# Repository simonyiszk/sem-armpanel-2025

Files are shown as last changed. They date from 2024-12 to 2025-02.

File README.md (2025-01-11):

# STM32F070 mikrokontrolleres ARM fejlesztőpanel a<br/> Schönherz Elektronikai Műhely 2025-ös<br/> alapozó tanfolyamához

Fícsörök:
- Kenyérvágódeszkával kompatibilis kialakítás
- Feliratozott lábak
- USB-C csatlakozó
- Integrált CMSIS-DAP programozó áramkör
- Visszajelző LED-ek: tápfeszültség, programozó/debugger üzemmód, valamint USER LED a PA6-os lábon
- RESET gomb

A mikrovezérlőhöz tartozó dokumentáció itt érhető el:<br/> [https://www.st.com/en/microcontrollers-microprocessors/stm32f070f6.html#documentation](https://www.st.com/en/microcontrollers-microprocessors/stm32f070f6.html#documentation)
  
DSCN0155

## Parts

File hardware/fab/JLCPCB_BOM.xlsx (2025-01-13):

Comment | Designator | Footprint | JLCPCB Part #（optional）
100n | C5,C2,C4 | C_0603_1608Metric | C14663
RED | D2,D3,D1 | LED_0603_1608Metric | C2286
LD1117S33TR_SOT223 | U2 | SOT-223-3_TabPin2 | C6186
10u | C3,C1 | C_0805_2012Metric | C15850
10k | R6,R7,R5 | R_0603_1608Metric | C25804
STM32F030F4Px | U1 | TSSOP-20_4.4x6.5mm_P0.65mm | C86951
1A | F1 | Fuse_1206_3216Metric | C883131
1k | R1,R2,R8 | R_0603_1608Metric | C21190
5k1 | R4,R3 | R_0603_1608Metric | C23186
CH32V203G6U6 | U3 | QFN-28-1EP_4x4mm_P0.4mm_EP2.8x2.8mm | C5142280
USB_C_Receptacle_USB2.0_16P | J1 | USB_C_Receptacle_G-Switch_GT-USB-7010ASV | C2927038

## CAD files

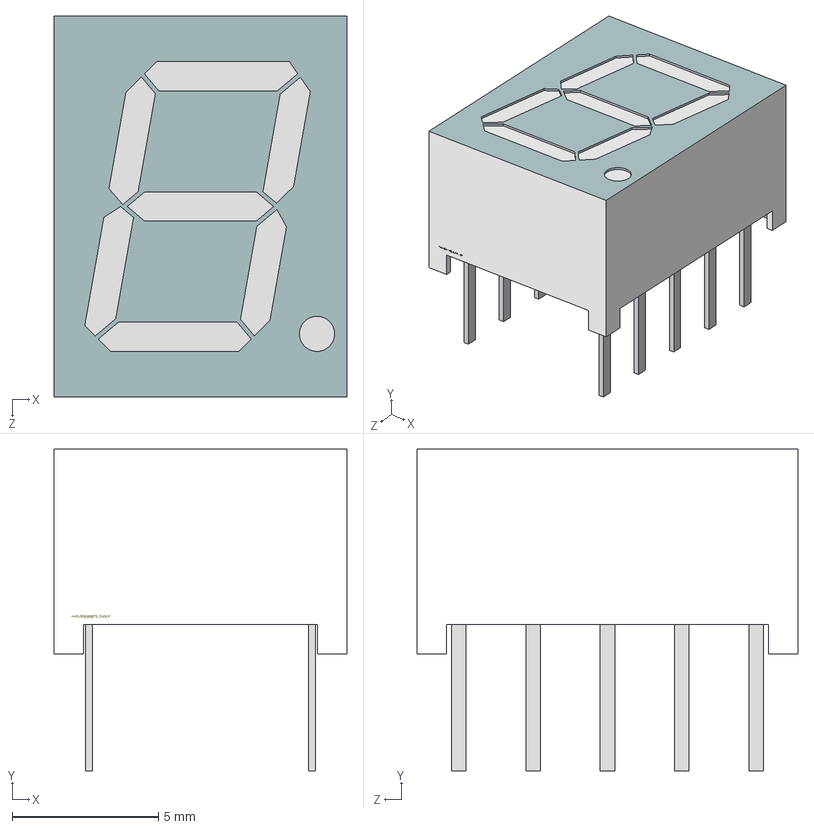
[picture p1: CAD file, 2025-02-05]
alappanel/SA39-11.STEP
10.0 x 11.0 x 13.0 mm

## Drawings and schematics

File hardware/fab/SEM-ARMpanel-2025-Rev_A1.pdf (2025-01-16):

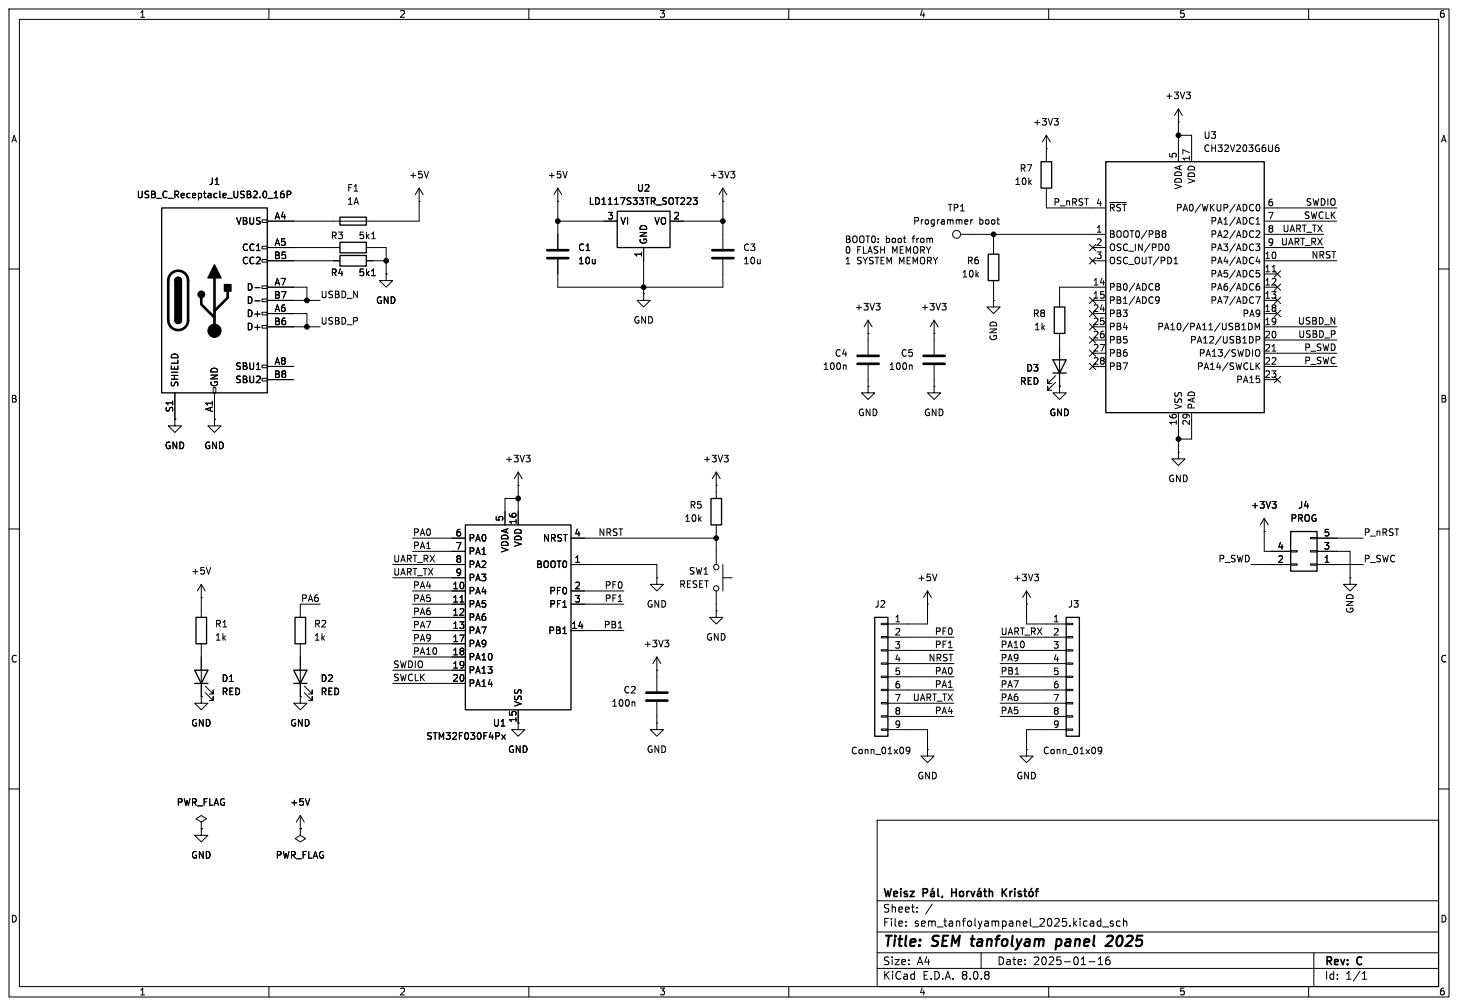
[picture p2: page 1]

Id: 1/1 Title: SEM tanfolyam panel 2025

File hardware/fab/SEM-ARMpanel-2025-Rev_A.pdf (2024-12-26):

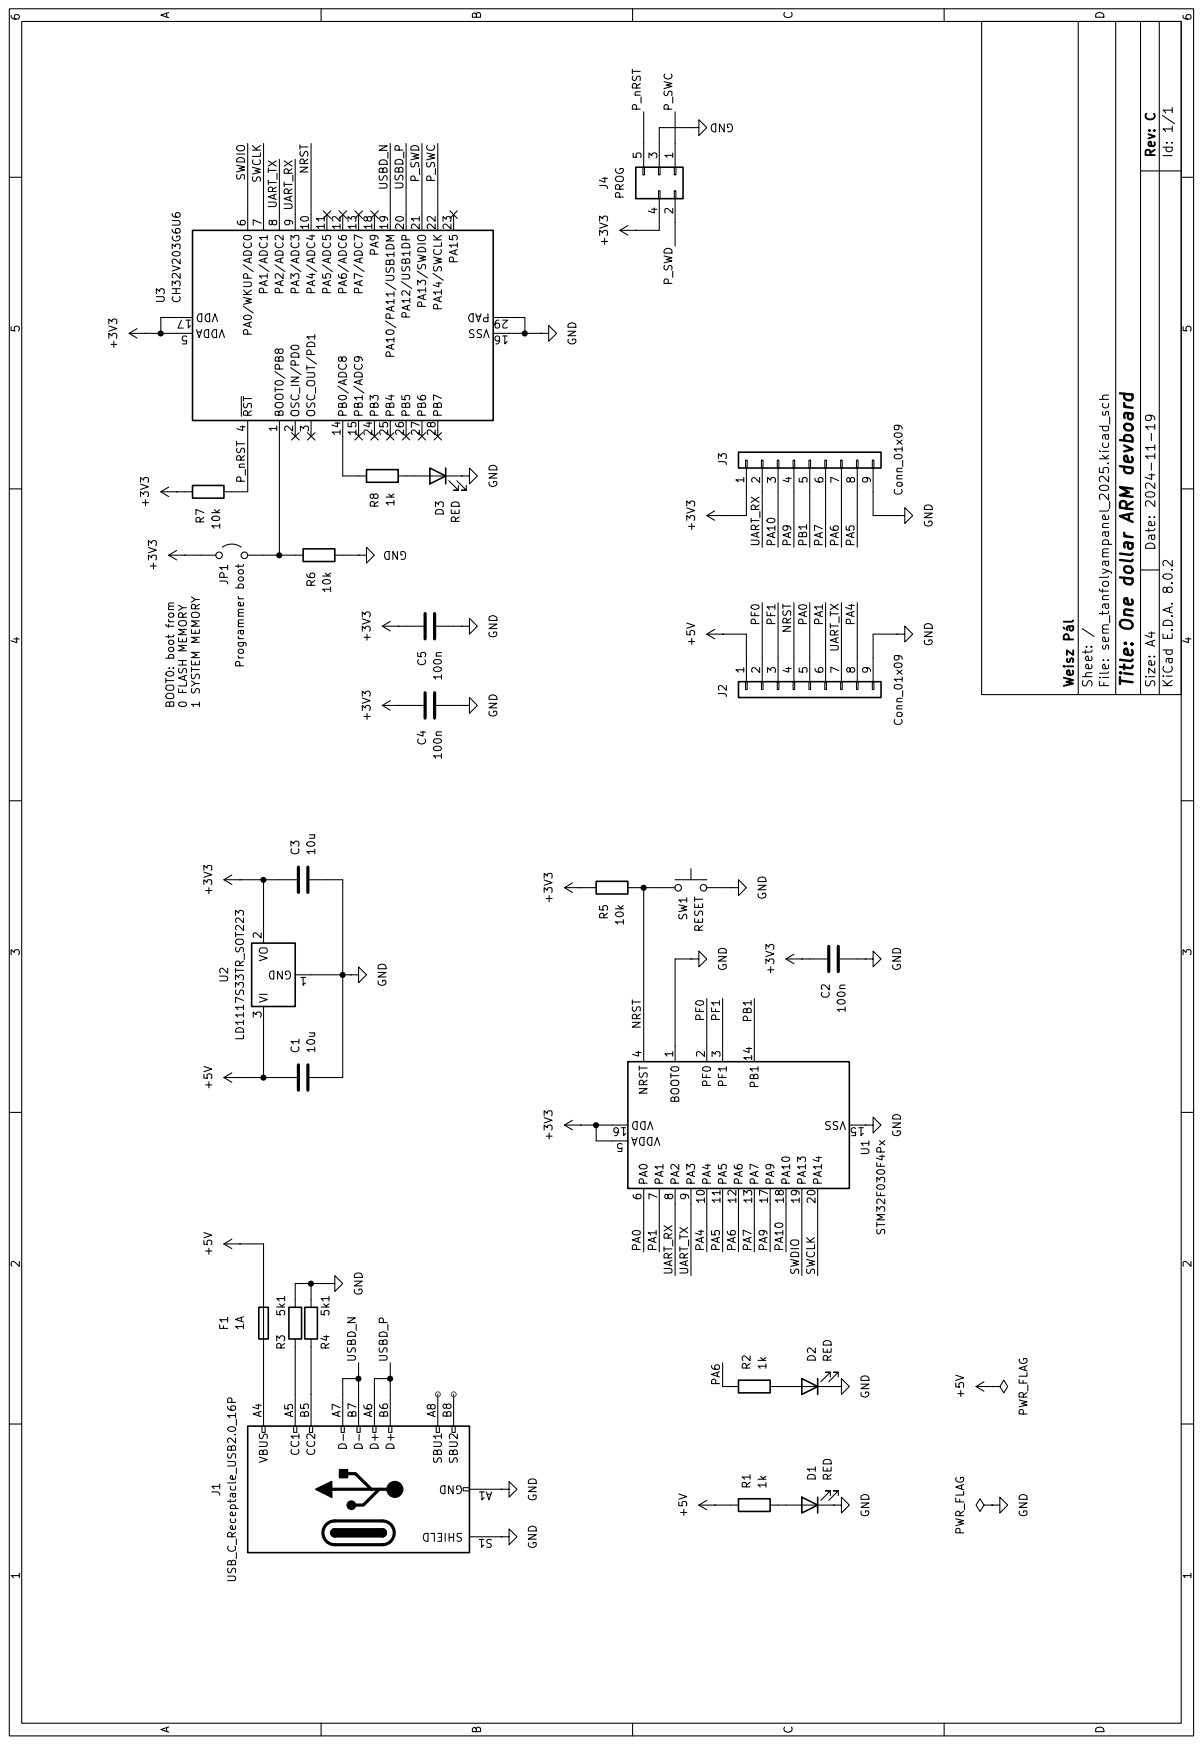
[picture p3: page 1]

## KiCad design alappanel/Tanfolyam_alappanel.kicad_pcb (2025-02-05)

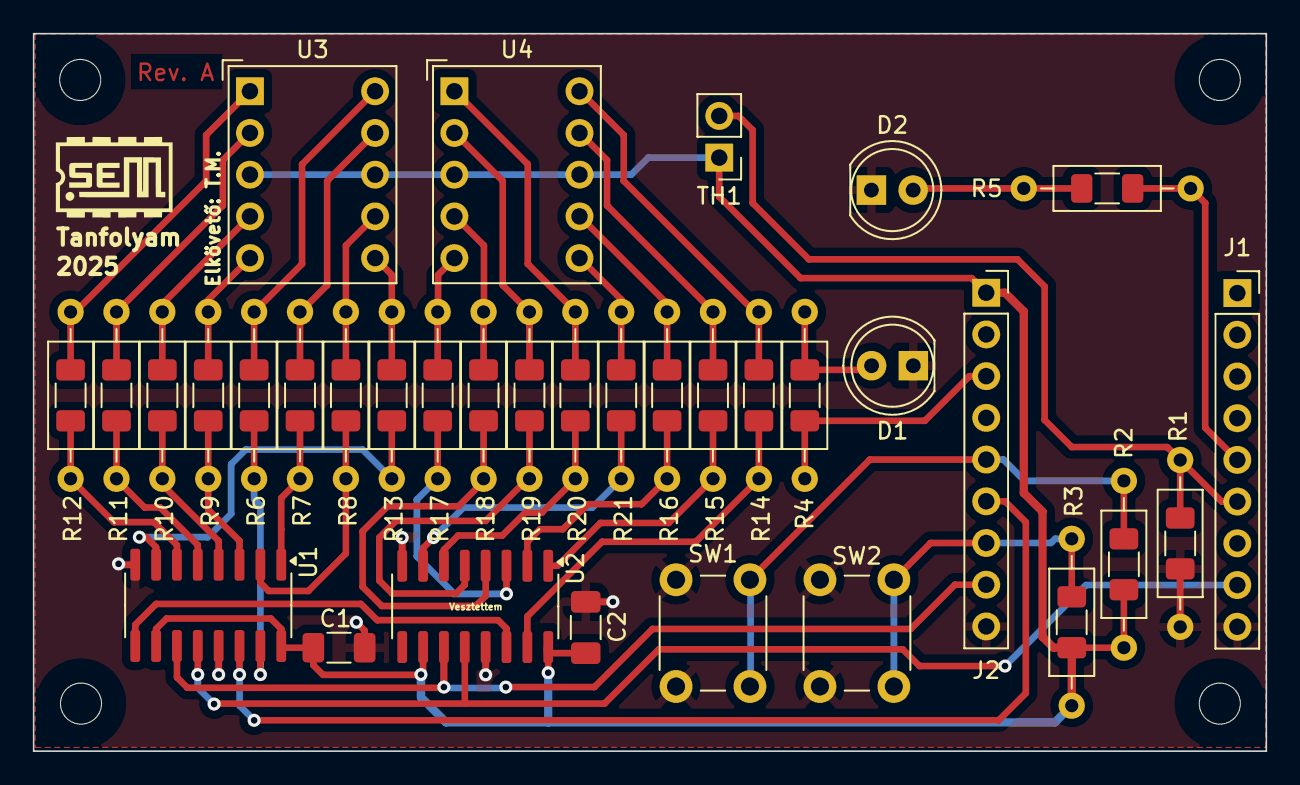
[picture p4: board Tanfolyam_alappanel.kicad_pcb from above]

Board: 2 copper layers, 75.1 x 43.7 mm, 34 parts (0 on the bottom side), 45 nets.

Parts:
C1, C2: 100n; C_1206_3216Metric_Pad1.33x1.80mm_HandSolder
D1, D2: LED; LED_D5.0mm
J1, J2: Connector; PinSocket_1x09_P2.54mm_Vertical
R1, R2, R3: 10k; R_1206_THT
R4, R5, R6, R7, R8, R9, R10, R11, R12, R13, R14, R15, R16, R17, R18, R19, R20, R21: 220; R_1206_THT
SW1, SW2: SW_Push; SW_PUSH_6mm
TH1: NTC; PinHeader_1x02_P2.54mm_Vertical
U1, U2: 74HC595; SOIC-16_3.9x9.9mm_P1.27mm
U3, U4: SA39-11SRWA; Sx39-1xxxxx

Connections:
+3.3V: C1.1, C2.1, J2.1, R2.1, R3.1, TH1.1, U1.10 (~SRCLR), U1.16 (VCC), U2.10 (~SRCLR), U2.16 (VCC), U3.3 (CA), U3.8 (CA), U4.3 (CA), U4.8 (CA)
/PA0: J1.5, R5.1
/PA1: J1.6, R1.1, TH1.2
/PA4: J1.8, U1.12 (RCLK), U2.12 (RCLK)
/PA5: J2.8, U1.11 (SRCLK), U2.11 (SRCLK)
/PA6: J2.7, R3.2, SW2.1
/PA7: J2.6, U1.14 (SER)
/PA10: J2.3, R4.1
/PB1: J2.5, R2.2, SW1.1
GND: C1.2, C2.2, D1.1 (K), D2.1 (K), J1.9, J2.9, R1.2, SW1.2, SW2.2, U1.8 (GND), U1.13 (~OE), U2.8 (GND), U2.13 (~OE)
unnamed: D1.2 (A), R4.2
unnamed: D2.2 (A), R5.2
unnamed: R6.1, U1.15 (QA)
unnamed: R7.1, U1.1 (QB)
unnamed: R8.1, U1.2 (QC)
unnamed: R9.1, U1.3 (QD)
unnamed: R10.1, U1.4 (QE)
unnamed: R11.1, U1.5 (QF)
unnamed: R12.1, U1.6 (QG)
unnamed: U1.9 (QH'), U2.14 (SER)
unnamed: R13.1, U1.7 (QH)
unnamed: R14.1, U2.15 (QA)
unnamed: R15.1, U2.1 (QB)
unnamed: R16.1, U2.2 (QC)
unnamed: R17.1, U2.3 (QD)
unnamed: R18.1, U2.4 (QE)
unnamed: R19.1, U2.5 (QF)
unnamed: R20.1, U2.6 (QG)
unnamed: R21.1, U2.7 (QH)
unnamed: R6.2, U3.10 (A)
unnamed: R7.2, U3.9 (B)
unnamed: R8.2, U3.7 (C)
unnamed: R9.2, U3.5 (D)
unnamed: R13.2, U3.6 (DP)
unnamed: R10.2, U3.4 (E)
unnamed: R11.2, U3.2 (F)
unnamed: R12.2, U3.1 (G)
unnamed: R14.2, U4.10 (A)
unnamed: R15.2, U4.9 (B)
unnamed: R16.2, U4.7 (C)
unnamed: R17.2, U4.5 (D)
unnamed: R21.2, U4.6 (DP)
unnamed: R18.2, U4.4 (E)
unnamed: R19.2, U4.2 (F)
unnamed: R20.2, U4.1 (G)

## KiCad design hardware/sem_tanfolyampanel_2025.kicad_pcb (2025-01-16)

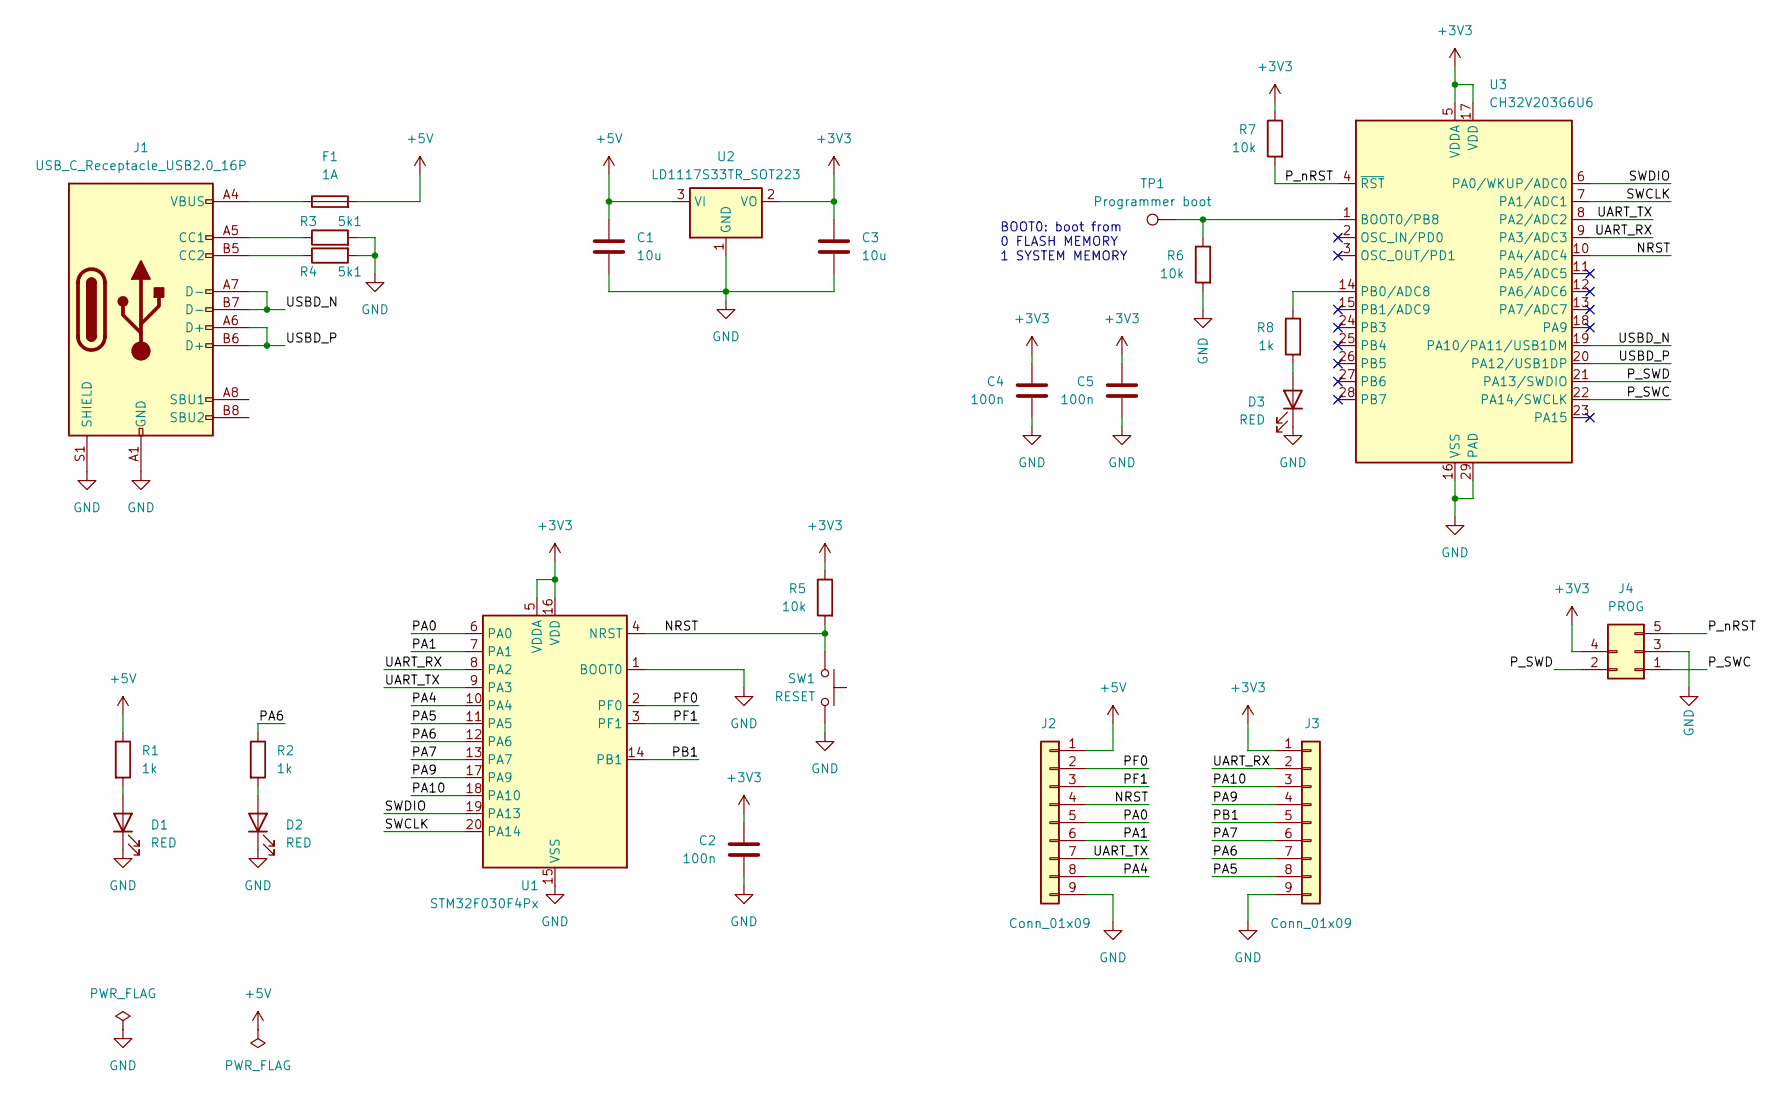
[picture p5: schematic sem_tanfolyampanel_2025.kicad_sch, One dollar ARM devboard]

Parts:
C1, C3: 10u; C_0805_2012Metric
C2, C4, C5: 100n; C_0603_1608Metric
D1, D2, D3: RED; LED_0603_1608Metric
F1: 1A; Fuse_1206_3216Metric
J1: USB_C_Receptacle_USB2.0_16P; USB_C_Receptacle_G-Switch_GT-USB-7010ASV
J2, J3: Conn_01x09; PinHeader_1x09_P2.54mm_Vertical
J4: PROG; ProgConnector_5pin
R1, R2, R8: 1k; R_0603_1608Metric
R3, R4: 5k1; R_0603_1608Metric
R5, R6, R7: 10k; R_0603_1608Metric
SW1: RESET; SW_SPST_TL3342
TP1: Programmer boot; TestPoint_THTPad_D1.5mm_Drill0.7mm
U1: STM32F030F4Px; TSSOP-20_4.4x6.5mm_P0.65mm
U2: LD1117S33TR_SOT223; SOT-223-3_TabPin2
U3: CH32V203G6U6; QFN-28-1EP_4x4mm_P0.4mm_EP2.8x2.8mm

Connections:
+3V3: C2.1, C3.1, C4.1, C5.1, J3.1, J4.4, R5.1, R7.1, U1.5 (VDDA), U1.16 (VDD), U2.2 (VO), U3.5 (VDDA), U3.17 (VDD)
+5V: C1.1, F1.2, J2.1, R1.1, U2.3 (VI)
/NRST: J2.4, R5.2, SW1.2, U1.4 (NRST), U3.10 (PA4/ADC4)
/PA0: J2.5, U1.6 (PA0)
/PA1: J2.6, U1.7 (PA1)
/PA4: J2.8, U1.10 (PA4)
/PA5: J3.8, U1.11 (PA5)
/PA6: J3.7, R2.1, U1.12 (PA6)
/PA7: J3.6, U1.13 (PA7)
/PA9: J3.4, U1.17 (PA9)
/PA10: J3.3, U1.18 (PA10)
/PB1: J3.5, U1.14 (PB1)
/PF0: J2.2, U1.2 (PF0)
/PF1: J2.3, U1.3 (PF1)
/P_SWC: J4.1, U3.22 (PA14/SWCLK)
/P_SWD: J4.2, U3.21 (PA13/SWDIO)
/P_nRST: J4.5, R7.2, U3.4 (~RST)
/SWCLK: U1.20 (PA14), U3.7 (PA1/ADC1)
/SWDIO: U1.19 (PA13), U3.6 (PA0/WKUP/ADC0)
/UART_RX: J3.2, U1.8 (PA2), U3.9 (PA3/ADC3)
/UART_TX: J2.7, U1.9 (PA3), U3.8 (PA2/ADC2)
/USBD_N: J1.A7 (D-), J1.B7 (D-), U3.19 (PA10/PA11/USB1DM)
/USBD_P: J1.A6 (D+), J1.B6 (D+), U3.20 (PA12/USB1DP)
GND: C1.2, C2.2, C3.2, C4.2, C5.2, D1.1 (K), D2.1 (K), D3.1 (K), J1.A1 (GND), J1.A12 (GND), J1.B1 (GND), J1.B12 (GND), J1.S1 (SHIELD), J2.9, J3.9, J4.3, R3.2, R4.2, R6.2, SW1.1, U1.1 (BOOT0), U1.15 (VSS), U2.1 (GND), U3.16 (VSS), U3.29 (PAD)
unnamed: D1.2 (A), R1.2
unnamed: D2.2 (A), R2.2
unnamed: D3.2 (A), R8.2
unnamed: F1.1, J1.A4 (VBUS), J1.A9 (VBUS), J1.B4 (VBUS), J1.B9 (VBUS)
unnamed: J1.A5 (CC1), R3.1
unnamed: J1.B5 (CC2), R4.1
unnamed: R6.1, TP1.1, U3.1 (BOOT0/PB8)
unnamed: R8.1, U3.14 (PB0/ADC8)

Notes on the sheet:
BOOT0: boot from 0 FLASH MEMORY 1 SYSTEM MEMORY

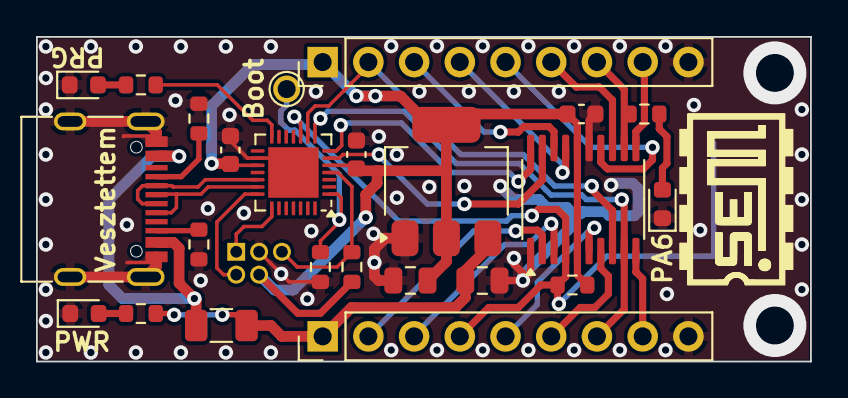
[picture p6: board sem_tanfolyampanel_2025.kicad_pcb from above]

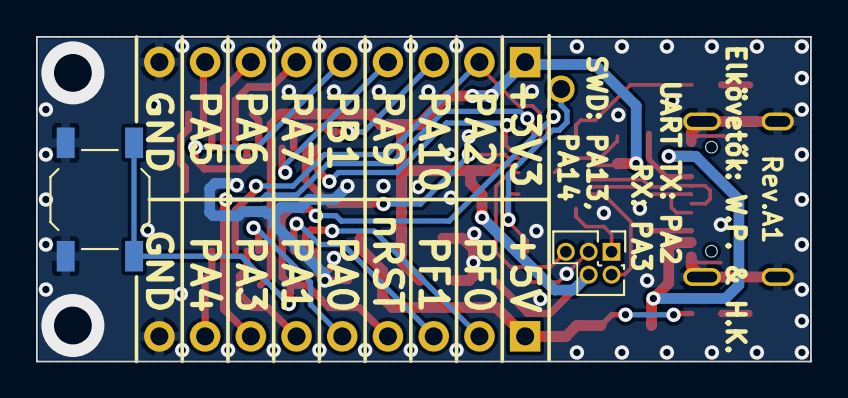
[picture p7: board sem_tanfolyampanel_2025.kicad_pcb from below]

Board: 2 copper layers, 43.0 x 18.0 mm, 26 parts (2 on the bottom side), 32 nets.

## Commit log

2024-12-07 Initial commit with schematic and unrouted PCB
    [sem_tanfolyampanel_2025.kicad_pcb, sem_tanfolyampanel_2025.kicad_sch]
2024-12-08 First iteration of PCB routing
    [sem_tanfolyampanel_2025.kicad_pcb, sem_tanfolyampanel_2025.kicad_sch]
2024-12-17 Rerouting and finalizing.
    [sem_tanfolyampanel_2025.kicad_pcb, sem_tanfolyampanel_2025.kicad_sch]
2024-12-26 Prototype sent to fab.
    [sem_tanfolyampanel_2025.kicad_pcb]
2025-01-09 Add interactive BoM for Rev.A
2025-01-11 Add config files for platformio project template
    [sem_tanfolyampanel_2025.kicad_pcb, sem_tanfolyampanel_2025.kicad_sch]
2025-01-13 Added BOM and panelization script.
    [JLCPCB_BOM.xlsx]
2025-01-16 Sent to fab.
    [sem_tanfolyampanel_2025.kicad_sch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]
2025-02-05 Added base board. Sent to fab.
    [SA39-11.STEP, Tanfolyam_alappanel.kicad_pcb, Tanfolyam_alappanel.kicad_sch]
